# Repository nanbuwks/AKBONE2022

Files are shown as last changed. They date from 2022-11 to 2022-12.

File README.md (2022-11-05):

# AKBONE2022

秋葉原ロボット部のトレーニングボード。
2022リリースはLEDパネルキットです。

初期コンセプトとAlpha版の説明
「AKBONE2022 で LED パネルを使ったオープンソーストレーニングキットを考える」
https://qiita.com/nanbuwks/items/5271dedf196623d452a0

AVTOKYO2022で頒布したBeta1版の説明
「LEDパネルキットAKBONE2022で楽しもう！ Beta1版」
https://qiita.com/nanbuwks/items/4317031bdf3bdcfafbf8

AKBONE2022の開発環境構築
「LEDパネルキット AKBONE2022 の環境構築を自分でやってみる
https://qiita.com/nanbuwks/items/d4523ebfb9cabdae90c5

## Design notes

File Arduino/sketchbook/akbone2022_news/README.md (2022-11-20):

# AKBONE2022 News

## はじめに
本サンプルソフトではP2高解像度LEDパネル(64x128)を接続したAKBONE2022において、Yahoo Newsを横スクロール表示します。


## 事前準備
SSL ( https )ページを取得するには、ブラウザと同じように公開鍵を含んだルート証明書をマイコンに保存しておく必要があります。
private.hppにあらかじめ、以下の記事を参考にYahoo! Japan RSS ニュースサイトのルート証明書を取得しておいてください。  
private.hppには仮の鍵が記載してあります。

https://www.mgo-tec.com/blog-entry-arduino-esp32-ssl-stable-root-ca.html/2

上記記事から、Chromeの証明書ビューアの表示と操作方法が変更になっています。証明書の取得は、詳細タブの証明書のフィールドで、サブジェクトの公開鍵を選択後、エクスポートボタンを押下してください。

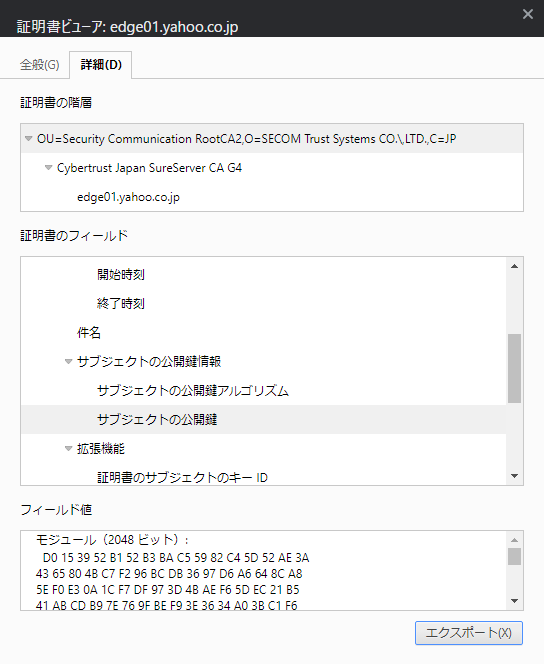
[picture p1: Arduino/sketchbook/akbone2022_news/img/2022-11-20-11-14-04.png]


## ビルド時の注意事項
スケッチが1MBを超えてしまうので、Arduino IDEのPartition SizeをNo OTAなどに変更し2MBに拡大しておく必要があります。  
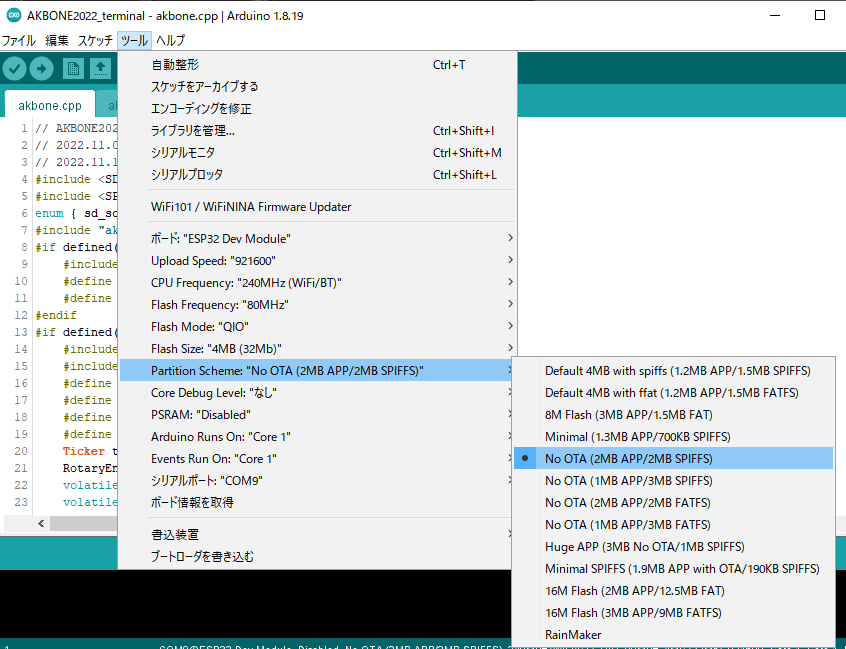
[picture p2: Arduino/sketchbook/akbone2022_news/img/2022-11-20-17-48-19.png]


PlatformIOの場合は、platformio.iniに以下を追加してください。  
```
board_build.partitions = no_ota.csv
```  

## 使用方法
初回起動時やWiFi環境が異なる場所での利用の場合、以下の画面時にSmartConfig(ESPTouch)でWiFiの設定を行ってください。  

https://www.espressif.com/en/products/software/esp-touch/overview



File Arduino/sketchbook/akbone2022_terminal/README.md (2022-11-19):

# AKBONE2022 Terminal

## はじめに
本サンプルソフトではP2高解像度LEDパネル（64x128)とLinuxボード（LicheeNano）を接続したAKBONE2022において、コンソール画面の表示とシリアル入出力を実現します。

## AKBONEの設定
- Lichee NANOを搭載
- TFCARDスロットは搭載しない
- JP1、JP2は 2-3をショートしTX2、RX2を選択

## 使用方法
LicheeNanoのシリアル出力は、LEDパネルとUSBシリアルに出力されます。
USBシリアルからの入力はLicheeNanoのシリアルに出力されます。
USBシリアルにTerminalソフトを115200bpsに設定して接続してください。

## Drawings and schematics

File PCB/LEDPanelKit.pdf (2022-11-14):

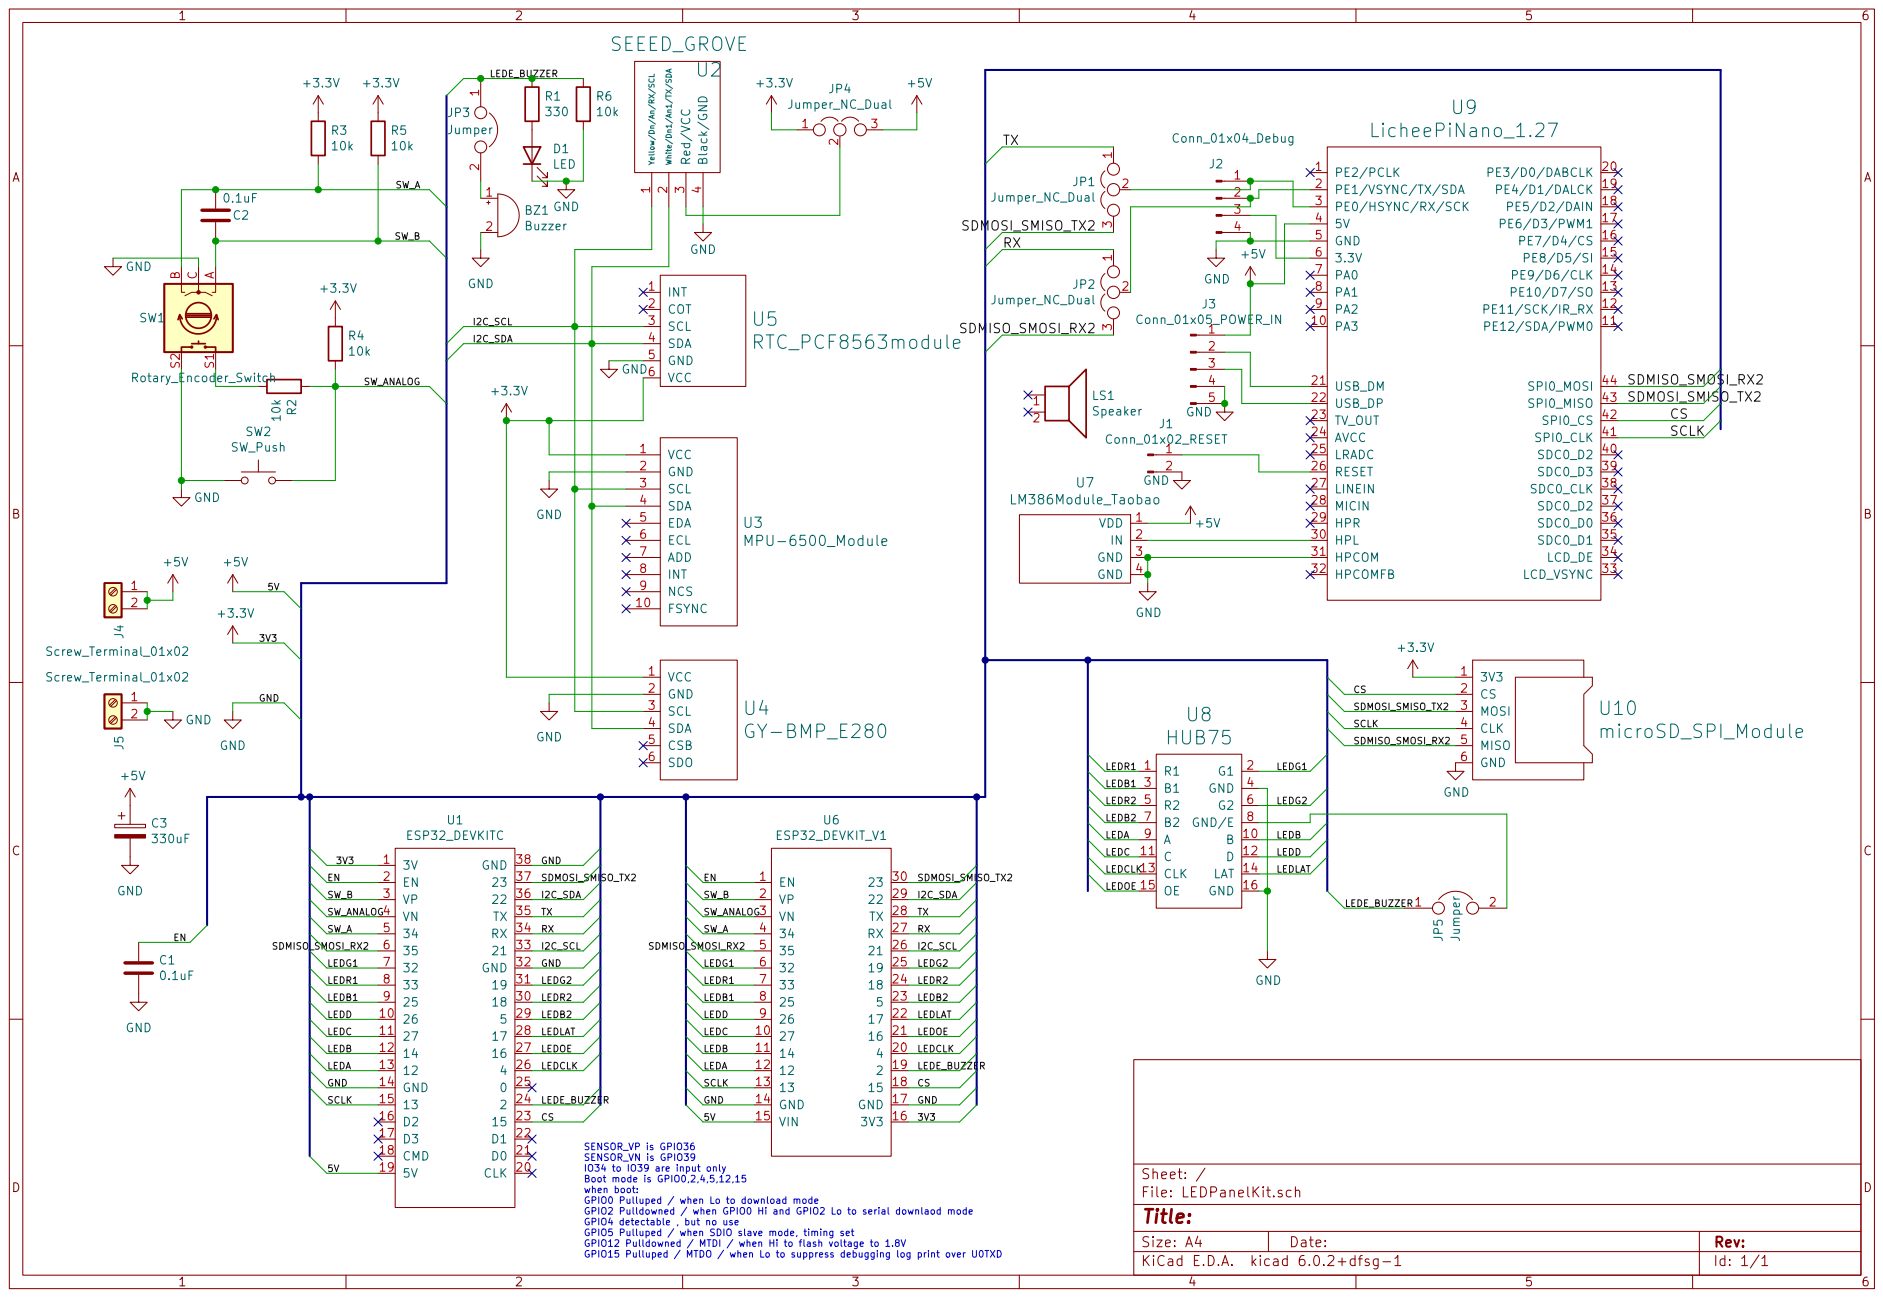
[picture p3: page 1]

IO34 to IO39 are input only Boot mode is GPIO0,2,4,5,12,15 when boot: GPIO0 Pulluped / when Lo to download mode GPIO2 Pulldowned / when GPIO0 Hi and GPIO2 Lo to serial downlaod mode GPIO4 detectable , but no use GPIO5 Pulluped / when SDIO slave mode, timing set GPIO12 Pulldowned / MTDI / when Hi to flash voltage to 1.8V GPIO15 Pulluped / MTDO / when Lo to suppress debugging log print over U0TXD

Id: 1/1 Title: File: LEDPanelKit.sch Sheet: /

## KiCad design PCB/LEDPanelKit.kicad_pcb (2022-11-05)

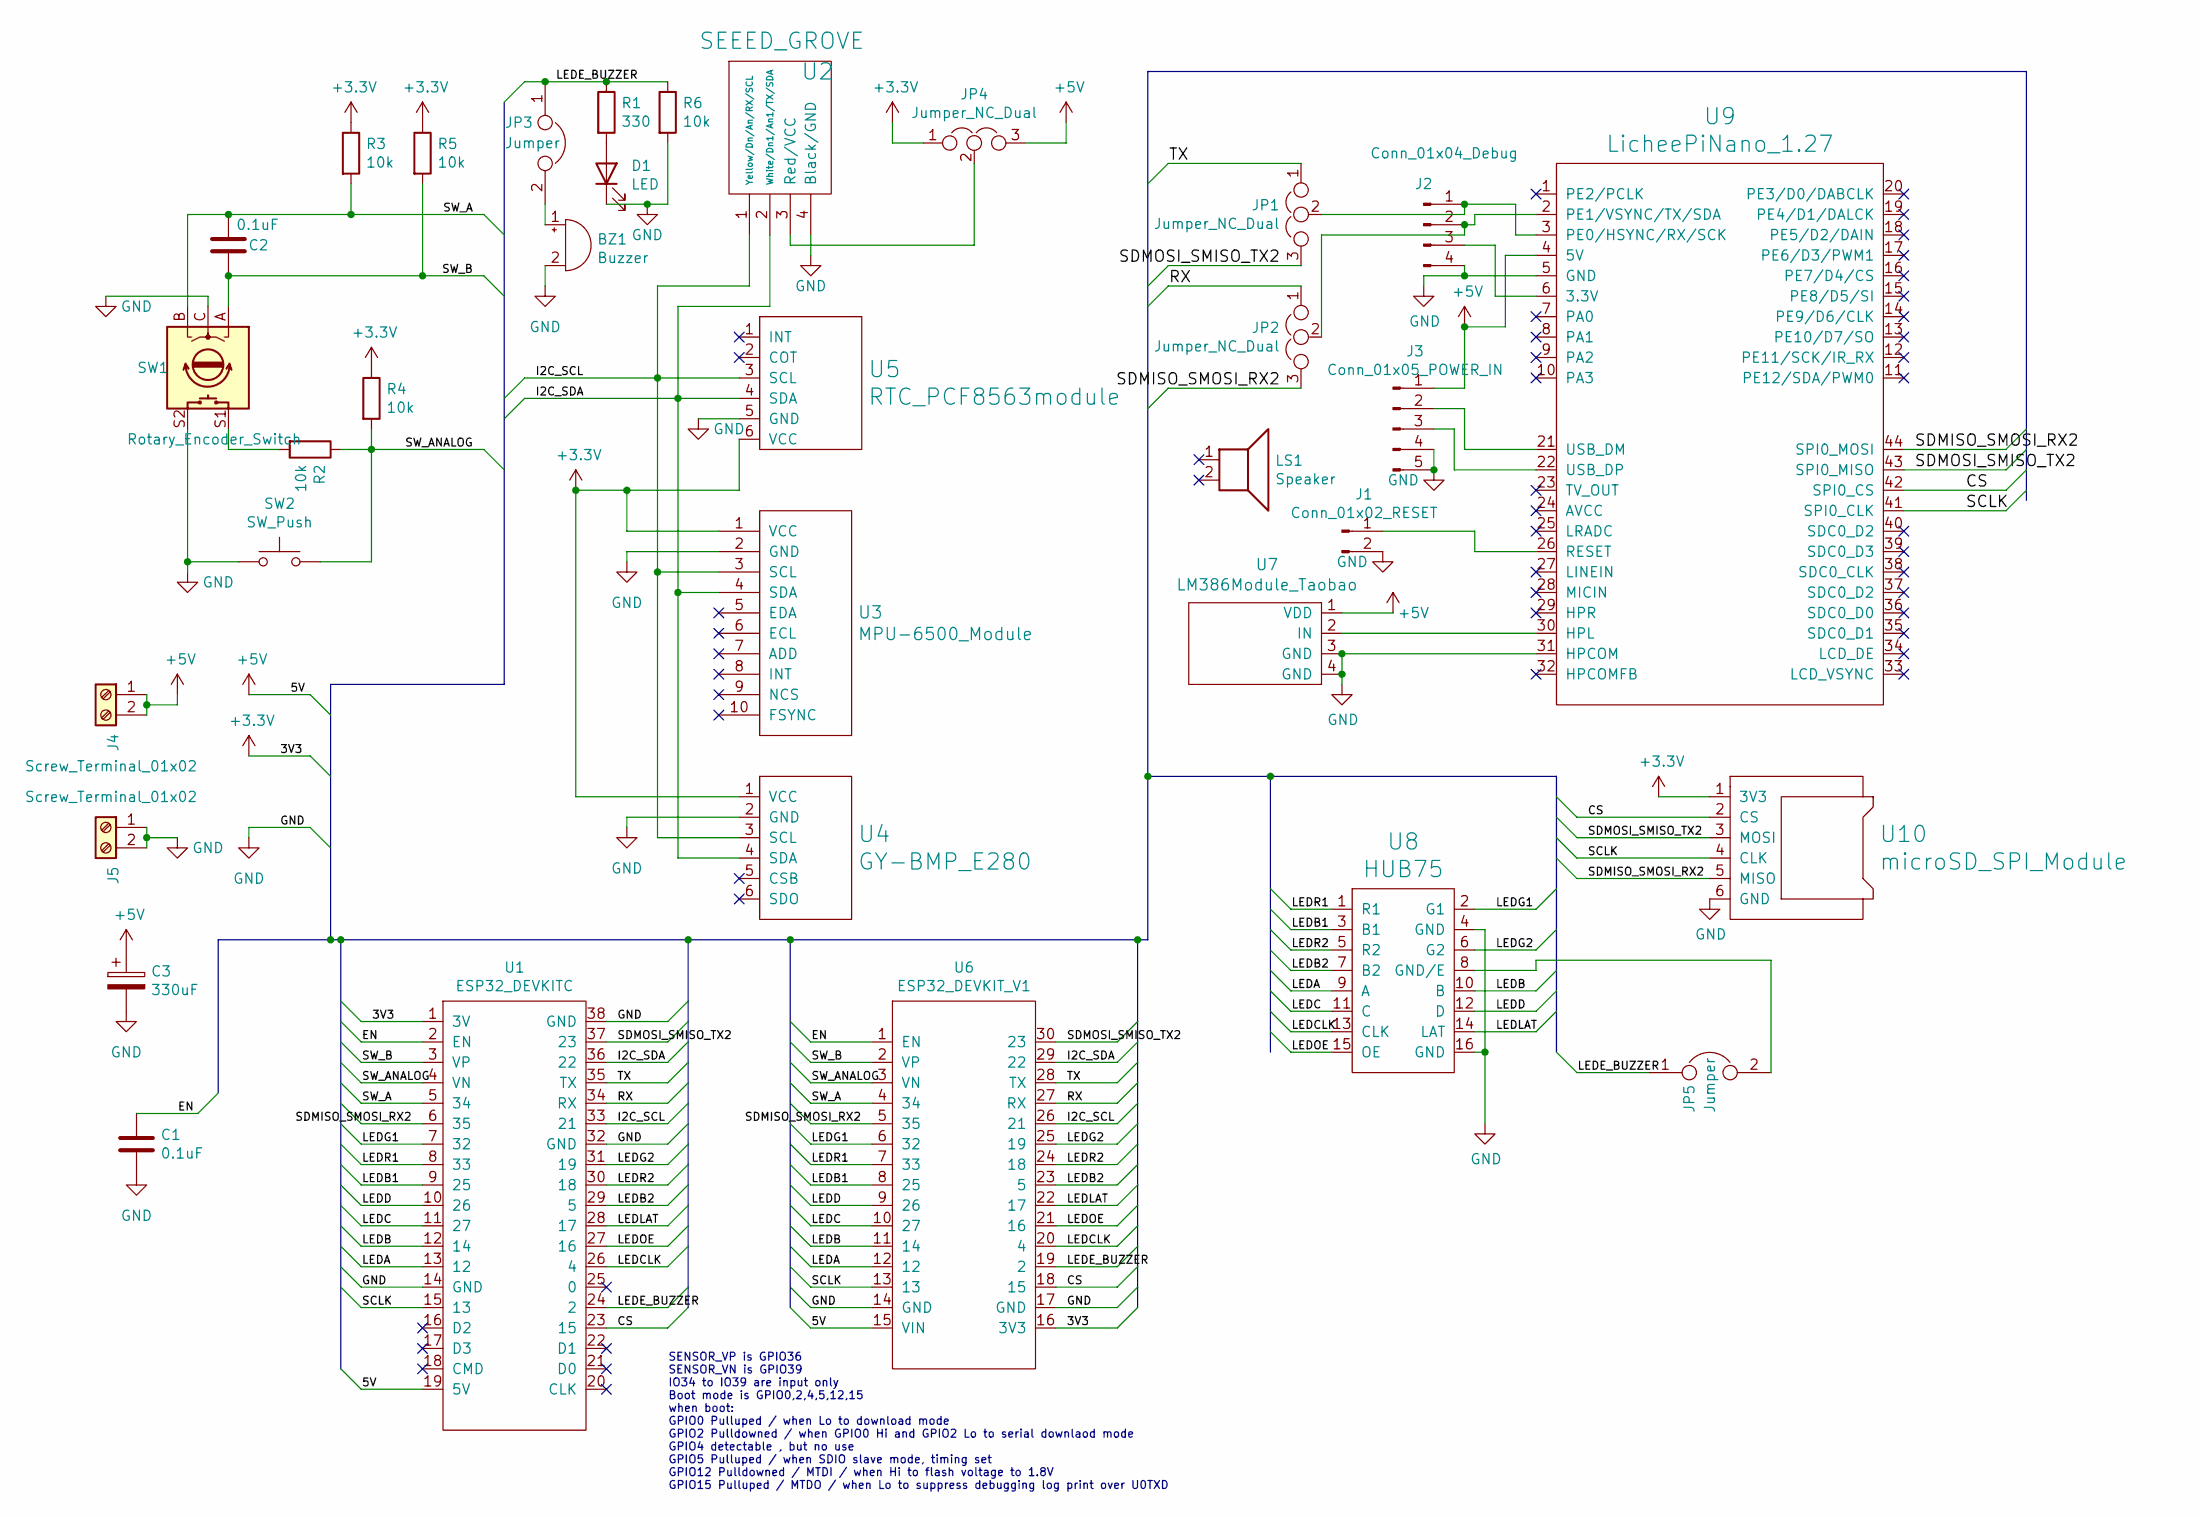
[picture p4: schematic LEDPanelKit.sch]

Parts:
BZ1: Buzzer; Buzzer_12x9.5RM7.6
C1, C2: 0.1uF; C_1206_3216Metric_Pad1.33x1.80mm_HandSolder
C3: 330uF; CP_Radial_D8.0mm_P5.00mm
D1: LED; LED_D5.0mm
J1: Conn_01x02_RESET; PinHeader_1x02_P2.54mm_Vertical
J2: Conn_01x04_Debug; PinHeader_1x04_P2.54mm_Vertical
J3: Conn_01x05_POWER_IN; PinHeader_1x05_P2.54mm_Vertical
J4, J5: Screw_Terminal_01x02; TerminalBlock_bornier-2_P5.08mm
JP1, JP2: Jumper_NC_Dual; PinHeader_1x03_P2.54mm_Vertical
JP3: Jumper; PinHeader_1x02_P2.54mm_Vertical
JP4: Jumper_NC_Dual; SolderJumper-3_P1.3mm_Bridged12_Pad1.0x1.5mm
JP5: Jumper; SolderJumper-2_P1.3mm_Open_TrianglePad1.0x1.5mm
LS1: Speaker; Speaker_Oval_2040
R1: 330; R_1206_3216Metric_Pad1.30x1.75mm_HandSolder
R2, R3, R4, R5, R6: 10k; R_1206_3216Metric_Pad1.30x1.75mm_HandSolder
SW1: Rotary_Encoder_Switch; RotaryEncoder_Alps_EC11E-Switch_Vertical_H20mm_CircularMoun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
SW2: SW_Push; SW_PUSH_6mm_H4.3mm
U1: ESP32_DEVKITC
U2: SEEED_GROVE; Seeedstudio_Grove_110990030_Vertical_4pin_2mmpitch
U3: MPU-6500_Module; MPU-6500_GY-6500
U4: GY-BMP_E280; GY_BMP_E280
U5: RTC_PCF8563module
U6: ESP32_DEVKIT_V1
U7: LM386Module_Taobao
U8: HUB75; IDC-Header_2x08_P2.54mm_Vertical
U9: LicheePiNano_1.27; Lichee_Pi_Nano
U10: microSD_SPI_Module; microSD_module_LCTechInc

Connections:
+3V3: JP4.1, R3.1, R4.1, R5.1, U1.1 (3V), U3.1 (VCC), U4.1 (VCC), U5.6 (VCC), U6.16 (3V3), U10.1 (3V3)
+5V: C3.1, J3.1, J4.1, J4.2, JP4.3, U1.19 (5V), U6.15 (VIN), U7.1 (VDD), U9.4 (5V)
/CS: U1.23 (15), U6.18 (15), U9.42 (SPI0_CS), U10.2 (CS)
/EN: C1.1, U1.2 (EN), U6.1 (EN)
/I2C_SCL: U1.33 (21), U2.1 (Yellow/Dn/An/RX/SCL), U3.3 (SCL), U4.3 (SCL), U5.3 (SCL), U6.26 (21)
/I2C_SDA: U1.36 (22), U2.2 (White/Dn1/An1/TX/SDA), U3.4 (SDA), U4.4 (SDA), U5.4 (SDA), U6.29 (22)
/LEDA: U1.13 (12), U6.12, U8.9 (A)
/LEDB: U1.12 (14), U6.11 (14), U8.10 (B)
/LEDB1: U1.9 (25), U6.8 (25), U8.3 (B1)
/LEDB2: U1.29 (5), U6.23 (5), U8.7 (B2)
/LEDC: U1.11 (27), U6.10 (27), U8.11 (C)
/LEDCLK: U1.26 (4), U6.20 (4), U8.13 (CLK)
/LEDD: U1.10 (26), U6.9 (26), U8.12 (D)
/LEDE_BUZZER: JP3.1, JP5.1, R1.1, R6.1, U1.24 (2), U6.19 (2)
/LEDG1: U1.7 (32), U6.6 (32), U8.2 (G1)
/LEDG2: U1.31 (19), U6.25 (19), U8.6 (G2)
/LEDLAT: U1.28 (17), U6.22 (17), U8.14 (LAT)
/LEDOE: U1.27 (16), U6.21 (16), U8.15 (OE)
/LEDR1: U1.8 (33), U6.7 (33), U8.1 (R1)
/LEDR2: U1.30 (18), U6.24 (18), U8.5 (R2)
/RX: JP2.1, U1.34 (RX), U6.27 (RX)
/SCLK: U1.15 (13), U6.13, U9.41 (SPI0_CLK), U10.4 (CLK)
/SDMISO_SMOSI_RX2: JP2.3, U1.6 (35), U6.5 (35), U9.44 (SPI0_MOSI), U10.5 (MISO)
/SDMOSI_SMISO_TX2: JP1.3, U1.37 (23), U6.30 (23), U9.43 (SPI0_MISO), U10.3 (MOSI)
/SW_A: C2.2, R3.2, SW1.B, U1.5 (34), U6.4 (34)
/SW_ANALOG: R2.1, R4.2, SW2.2, U1.4 (VN), U6.3 (VN)
/SW_B: C2.1, R5.2, SW1.A, U1.3 (VP), U6.2 (VP)
/TX: JP1.1, U1.35 (TX), U6.28 (TX)
GND: BZ1.2 (+), C1.2, C3.2, D1.1 (K), J1.2, J2.4, J3.4, J3.5, J5.1, J5.2, R6.2, SW1.C, SW1.S2, SW2.1, U1.14 (GND), U1.32 (GND), U1.38 (GND), U2.4 (Black/GND), U3.2 (GND), U4.2 (GND), U5.5 (GND), U6.14 (GND), U6.17 (GND), U7.3 (GND), U7.4 (GND), U8.4 (GND), U8.16 (GND), U9.5 (GND), U9.31 (HPCOM), U10.6 (GND)
unnamed: BZ1.1 (-), JP3.2
unnamed: D1.2 (A), R1.2
unnamed: J1.1, U9.26 (RESET)
unnamed: J2.1, JP1.2, U9.3 (PE0/HSYNC/RX/SCK)
unnamed: J2.2, JP2.2, U9.2 (PE1/VSYNC/TX/SDA)
unnamed: J2.3, U9.6 (3.3V)
unnamed: J3.2, U9.21 (USB_DM)
unnamed: J3.3, U9.22 (USB_DP)
unnamed: JP4.2, U2.3 (Red/VCC)
unnamed: JP5.2, U8.8 (GND/E)
unnamed: R2.2, SW1.S1
unnamed: U7.2 (IN), U9.30 (HPL)

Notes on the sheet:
SENSOR_VP is GPIO36 SENSOR_VN is GPIO39 IO34 to IO39 are input only Boot mode is GPIO0,2,4,5,12,15 when boot: GPIO0 Pulluped / when Lo to download mode GPIO2 Pulldowned / when GPIO0 Hi and GPIO2 Lo to serial downlaod mode GPIO4 detectable , but no use GPIO5 Pulluped / when SDIO slave mode, timing s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

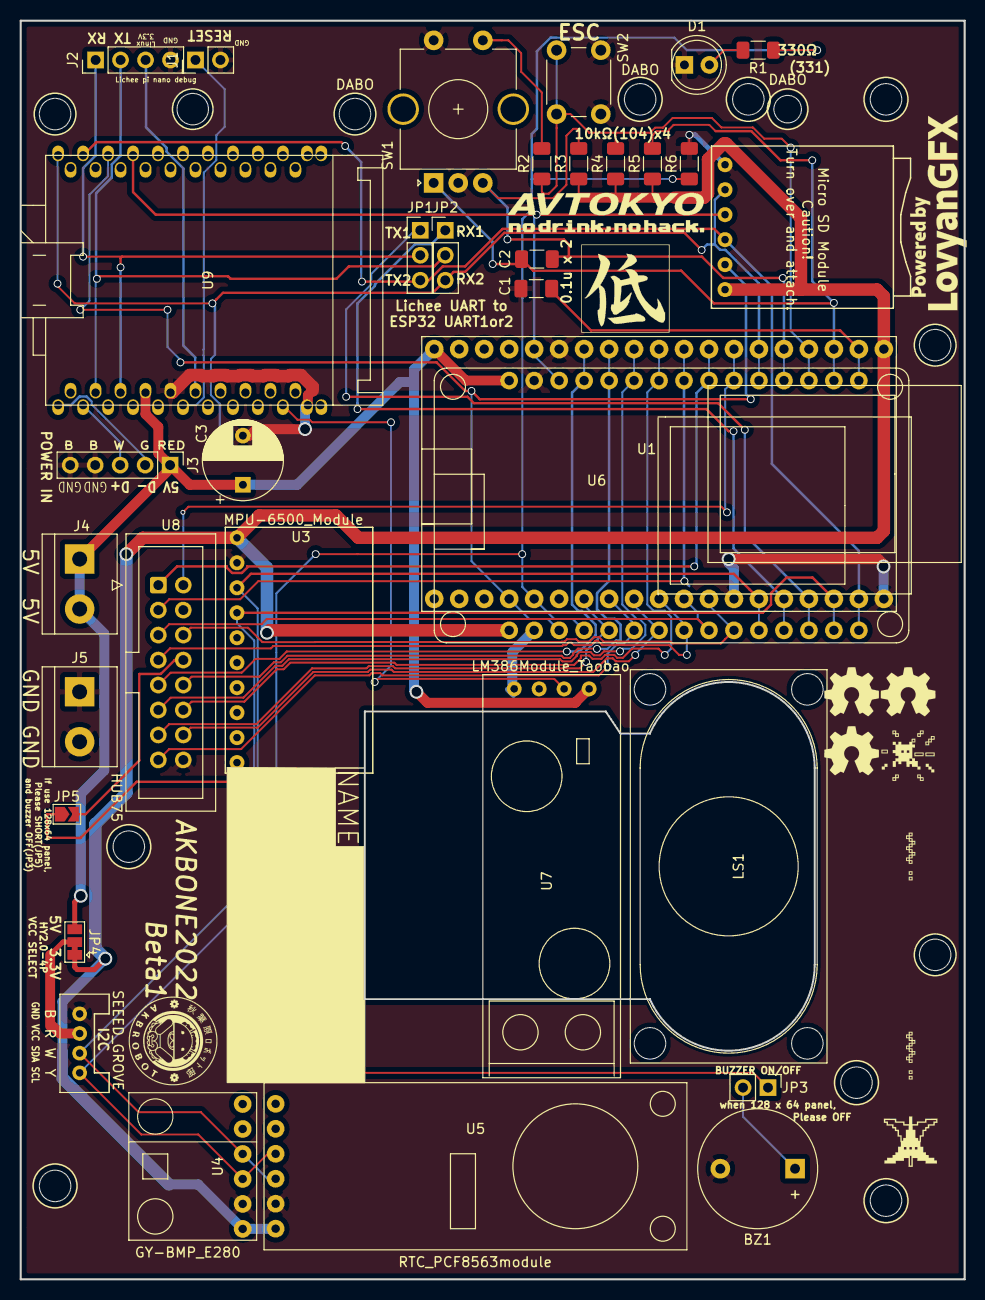
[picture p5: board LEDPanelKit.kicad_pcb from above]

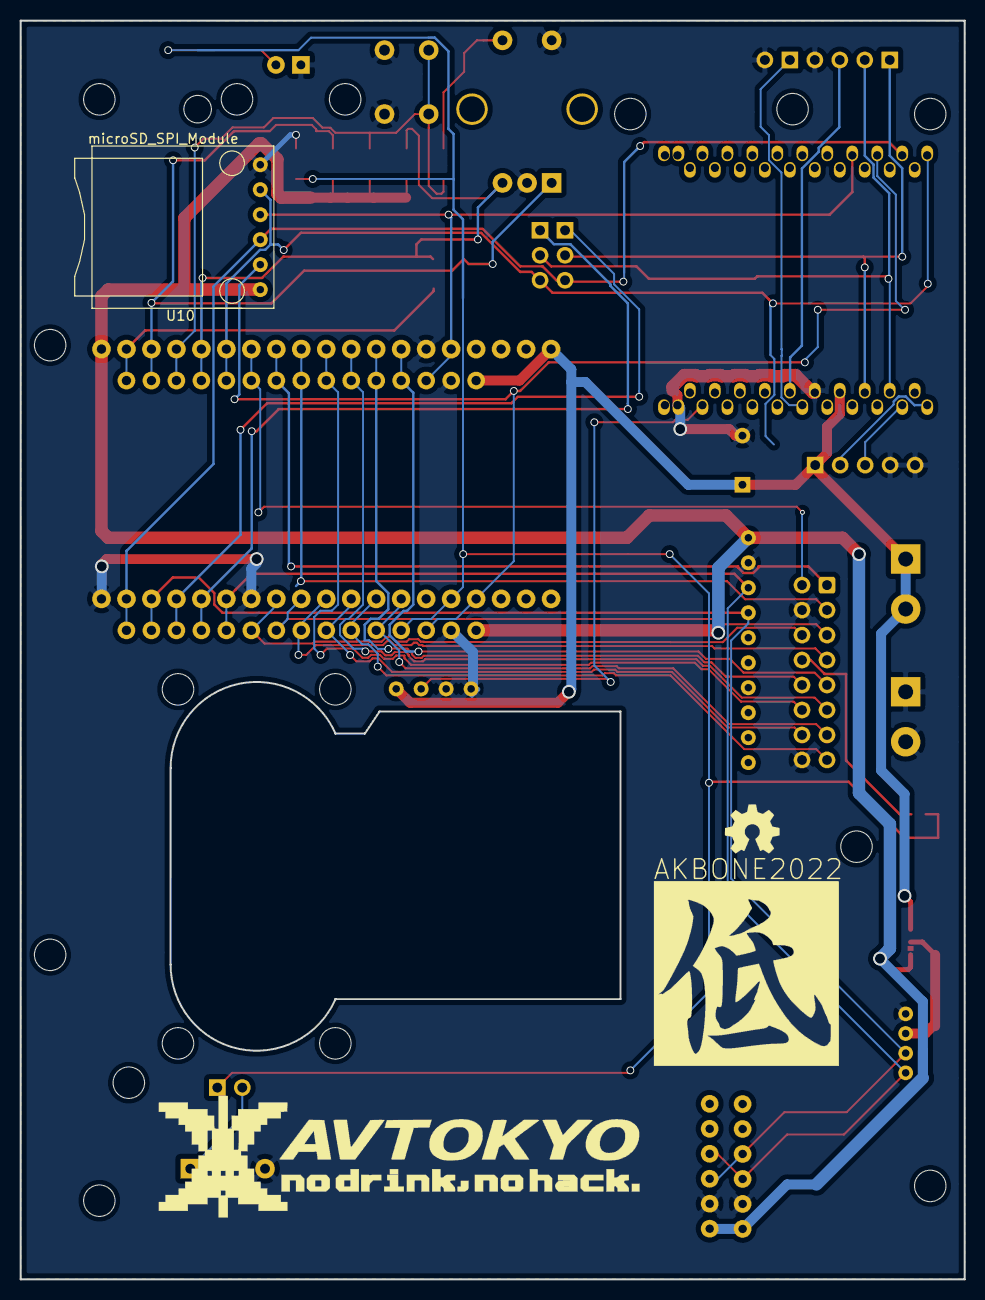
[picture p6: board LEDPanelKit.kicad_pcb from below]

Board: 2 copper layers, 96.0 x 128.0 mm, 38 parts (2 on the bottom side), 41 nets.

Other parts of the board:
OSHW: 1.1; OSHW_LOGL_SYLK_5mm
OSHW#2, OSHW#3, OSHW#4: 1.1; OSHW_LOGL_SYLK_5mm

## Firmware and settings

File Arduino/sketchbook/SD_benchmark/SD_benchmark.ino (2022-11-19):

#define TEST_FILE_SIZE (4 * 1024 * 1024)


#include "FS.h"
#include "SD.h" // LGFXより先に読み込む必要がある
#include "SD_MMC.h"

#define LGFX_USE_V1
#include <LovyanGFX.hpp>

// #define PANEL_64x32
#define PANEL_128x64



struct LGFX_HUB75 : public lgfx::LGFX_Device
{
  static void convertCoordinate(uint_fast16_t &x, uint_fast16_t &y)
  {/*
    if (x & 8) { x = x ^ 7; }
    */
    if ( x < 256)
    {
      x = x ^ 127;
      y = y ^ 63;
    }
  }

  lgfx::Bus_HUB75 _bus_instance;
// 1枚だけで使用する場合はこちら
  lgfx::Panel_HUB75 _panel_instance;

// 2枚以上接続する場合はこちら
// lgfx::Panel_HUB75_Multi _panel_instance;

 
  LGFX_HUB75(void)
  {
    // X 座標が8ドット単位で逆順になるパネルの場合、座標変換関数を使用するよう指定する
   // _panel_instance.convertCoordinate = convertCoordinate;
    
    {
      auto cfg = _bus_instance.config();
      cfg.port = 1;
   /*   
HUB75 Standard set RGB configuration
     +-+-+
   R1|o|o|G1
   G1|o|o|GND
   R2|o|o|G2
   G2 o|o|GND
   A  o|o|B
   C |o|o|D
  CLK|o|o|LAT
   OE|o|o|GND
     +-+-+

HUB75E + BRG panel set BRG configuration
     +-+-+
   B1|o|o|R1
   G1|o|o|GND
   B2|o|o|R2
   G2 o|o|E
   A  o|o|B
   C |o|o|D
  CLK|o|o|LAT
   OE|o|o|GND
     +-+-+

some panel has no D,E line, please set RGB configuration
     +-+-+
   R1|o|o|G1
   G1|o|o|GND
   R2|o|o|G2
   G2 o|o|GND
   A  o|o|B
   C |o|o|D
  CLK|o|o|LAT
   OE|o|o|GND
     +-+-+
     
*/
   
   // RGB configuration
      cfg.pin_r1 = GPIO_NUM_33; // R1
      cfg.pin_r2 = GPIO_NUM_18; // R2
      cfg.pin_g1 = GPIO_NUM_32; // G1
      cfg.pin_g2 = GPIO_NUM_19; // G2
      cfg.pin_b1 = GPIO_NUM_25; // B1
      cfg.pin_b2 = GPIO_NUM_5 ; // B2
  /*/ // BRG configuration
      cfg.pin_r1 = GPIO_NUM_32; // R1
      cfg.pin_r2 = GPIO_NUM_19; // R2
      cfg.pin_g1 = GPIO_NUM_25; // G1
      cfg.pin_g2 = GPIO_NUM_5 ; // G2
      cfg.pin_b1 = GPIO_NUM_33; // B1
      cfg.pin_b2 = GPIO_NUM_18; // B2
  //*/
      cfg.pin_lat = GPIO_NUM_17; // LAT
      cfg.pin_oe  = GPIO_NUM_16; // OE
      cfg.pin_clk = GPIO_NUM_4 ; // CLK

      cfg.pin_addr_a = GPIO_NUM_12;
      cfg.pin_addr_b = GPIO_NUM_14;
      cfg.pin_addr_c = GPIO_NUM_27;
      cfg.pin_addr_d = GPIO_NUM_26;
      cfg.pin_addr_e = GPIO_NUM_2;

      // 1秒間の更新回数を設定
      cfg.refresh_rate = 300;

      // パネルの行選択の仕様に応じて指定する
       cfg.address_mode = cfg.address_shiftreg;
      //cfg.address_mode = cfg.address_binary;

      // LEDドライバの初期化コマンドを指定する
      // cfg.initialize_mode = cfg.initialize_none;
      cfg.initialize_mode = cfg.initialize_fm6124;

      // DMA用のタスクの優先度 (FreeRTOSのタスク機能を使用)
      cfg.task_priority = 2;

      // DMA用のタスクに使用するCPUコア設定 (FreeRTOSのタスク機能を使用)
      cfg.task_pinned_core = PRO_CPU_NUM;
      // cfg.task_pinned_core = APP_CPU_NUM;

      _bus_instance.config(cfg);
      _panel_instance.setBus(&_bus_instance);
    }

    {
      auto cfg = _panel_instance.config();

      // ここでパネルサイズを指定する
      // 複数枚並べる場合は全体の縦横サイズを指定
      //  ----- 1枚構成  ここから
      cfg.memory_width  = cfg.panel_width  = 128;
      cfg.memory_height = cfg.panel_height = 64;

      _panel_instance.config(cfg);
      setPanel(&_panel_instance);
      //*/ 1枚構成 ここまで
      
      /* 複数枚構成 ここから 
      
      cfg.memory_width  = cfg.panel_width  = 256;
      cfg.memory_height = cfg.panel_height = 128;

      _panel_instance.config(cfg);
      setPanel(&_panel_instance);
    }
    {
      auto cfg = _panel_instance.config_detail();

      // 構成パネルの総枚数を指定
      cfg.panel_count = 4;

      // パネル1枚の幅を指定
      cfg.single_width = 128;

      // パネル1枚の高さを指定
      cfg.single_height = 64;

      _panel_instance.config_detail(cfg);

      // 各パネルの配置座標を設定する
      _panel_instance.setPanelPosition( 1,   0,   0,2);
      _panel_instance.setPanelPosition( 0,  128,  0,2);
      _panel_instance.setPanelPosition( 2,  0,   64);
      _panel_instance.setPanelPosition( 3,  128,  64);
      */
      // 複数枚構成 ここまで

    }

  }
};

LGFX_HUB75 gfx;

#define CLK_PULSE digitalWrite(cfg.pin_clk, HIGH); digitalWrite(cfg.pin_clk, LOW);




void testWriteFile(fs::FS &fs, const char *path, uint8_t *buf, int len)
{
  unsigned long start_time = millis();
  Serial.printf("Test write %s\n", path);

  File file = fs.open(path, FILE_WRITE);
  if (!file) {
    Serial.println("Failed to open file for writing");
    return;
  }
  int loop = TEST_FILE_SIZE / len;
  while (loop--)
  {
    if (!file.write(buf, len)) {
      Serial.println("Write failed");
      return;
    }
  }
  file.flush();
  file.close();
  unsigned long time_used = millis() - start_time;
  Serial.printf("Write file used: %d ms, %f KB/s\n", time_used, (float)TEST_FILE_SIZE / time_used);
}

void testReadFile(fs::FS &fs, const char *path, uint8_t *buf, int len)
{
  unsigned long start_time = millis();
  Serial.printf("Test read %s\n", path);

  File file = fs.open(path);
  if (!file) {
    Serial.println("Failed to open file for reading");
    return;
  }
  int loop = TEST_FILE_SIZE / len;
  while (loop--)
  {
    if (!file.read(buf, len)) {
      Serial.println("Read failed");
      return;
    }
  }
  file.close();
  unsigned long time_used = millis() - start_time;
  Serial.printf("Read file used: %d ms, %f KB/s\n", time_used, (float)TEST_FILE_SIZE / time_used);
}

void testIO(fs::FS &fs)
{
  /* malloc will not reset all bytes to zero, so it is a random data */
  uint8_t *buf = (uint8_t*)malloc(64 * 1024);

  testWriteFile(fs, "/test_1k.bin", buf, 1024);
  testWriteFile(fs, "/test_2k.bin", buf, 2 * 1024);
  testWriteFile(fs, "/test_4k.bin", buf, 4 * 1024);
  testWriteFile(fs, "/test_8k.bin", buf, 8 * 1024);
  testWriteFile(fs, "/test_16k.bin", buf, 16 * 1024);
  testWriteFile(fs, "/test_32k.bin", buf, 32 * 1024);
  testWriteFile(fs, "/test_64k.bin", buf, 64 * 1024);

  testReadFile(fs, "/test_1k.bin", buf, 1024);
  testReadFile(fs, "/test_2k.bin", buf, 2 * 1024);
  testReadFile(fs, "/test_4k.bin", buf, 4 * 1024);
  testReadFile(fs, "/test_8k.bin", buf, 8 * 1024);
  testReadFile(fs, "/test_16k.bin", buf, 16 * 1024);
  testReadFile(fs, "/test_32k.bin", buf, 32 * 1024);
  testReadFile(fs, "/test_64k.bin", buf, 64 * 1024);
}

void setup() {

  Serial.begin(115200);

// LEDドライバのレジスタ設定
//fm6124init();

  gfx.init();
  gfx.setBrightness(255);



  /* test SD SPI Mode at HSPI */
  SPIClass spi = SPIClass(HSPI);
  spi.begin(13 /* SCK */, 35 /* MISO */, 23 /* MOSI */, 15 /* SS */);
  if (!SD.begin(15 /* SS */, spi, 80000000)) {
    Serial.println("Card Mount Failed");
    return;
  }
  testIO(SD);

}

void loop() {
}

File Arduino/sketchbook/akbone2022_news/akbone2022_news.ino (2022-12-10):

// AKBONE2022 AKBONE2022 Yahoo News
// 2022.11.18 K.Ohe New Create
// 2022.12.12 K.Ohe for P3 2nd Panel
#include "akbone.hpp"
#include <string.h>
#include "YahooNewsLib.hpp"

#if defined(PANEL_128x64)
    #define FONT          &fonts::lgfxJapanMincho_40
    #define FONT_SIZE     64
    #define FONT_MULTI   1.6
    #define SPRITE_SIZE  128
#else
    #define FONT          &fonts::lgfxJapanMincho_32
    #define FONT_SIZE     32
    #define SPRITE_SIZE   64
    #define FONT_MULTI    1.0
#endif
uint32_t WebGet_LastTime = 0;

//===========================================================
//	setup() ： arduino setup
//===========================================================
void setup() {
    WebGet_LastTime = 200000; //起動時に記事をGETするために、多めの数値で初期化しておく  

    akbone_setup();
    clearLED();
    gfx.setTextColor(TFT_BLUE, TFT_BLACK);
    wifiConnect();
    clearLED();
}

//===========================================================
//	loop() ： arduino main loop
//===========================================================
void loop()
{
    String str;
    uint16_t dly = 5;
    //=====================================================================
    // 180秒(3分)毎にYahoo Newsを取得
    //=====================================================================
    if((millis() - WebGet_LastTime) > 180000){        
        str = https_Web_Get("news.yahoo.co.jp", "/rss/topics/top-picks.xml", '\n', "</rss>", "<title>", "</title>", "<description>", "</description>", "◇");
        str = str + "　　　　　　　　　　　　　　　　　　　";
        WebGet_LastTime = millis();
    }
    //=====================================================================
    // Newsをスクロール表示
    //=====================================================================
    disp_scrollText(str, dly);
}

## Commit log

2022-11-05 Beta1 PCB
    [LEDPanelKit.kicad_pcb, LEDPanelKit.sch]
2022-11-05 add arduino sketchbook sample
2022-11-05 modify for sample program for newest LovyanGFX library.
2022-11-06 modify sample program for LovyanGFX library develop branch 6aef99
2022-11-06 add BME280 sample sketch
2022-11-06 add RTC sample sketch
2022-11-06 AVTOKYO demo sketch missing fix
    [avtokyo2022demo.ino]
2022-11-06 GYRO demo sketch add
2022-11-08 add video sample
2022-11-14 add schematics pdf
2022-11-19 update sample programs to fit to LovyanGFX develop branch revision 86f0ea3
2022-11-20 akbone2022_news README.md説明追加
2022-11-20 証明書の説明追加
